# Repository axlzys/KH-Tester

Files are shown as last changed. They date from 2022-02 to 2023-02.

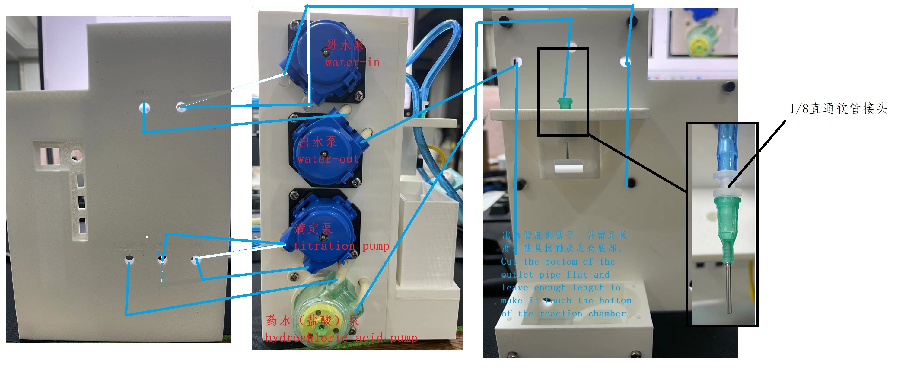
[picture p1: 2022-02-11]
管路连接.jpg

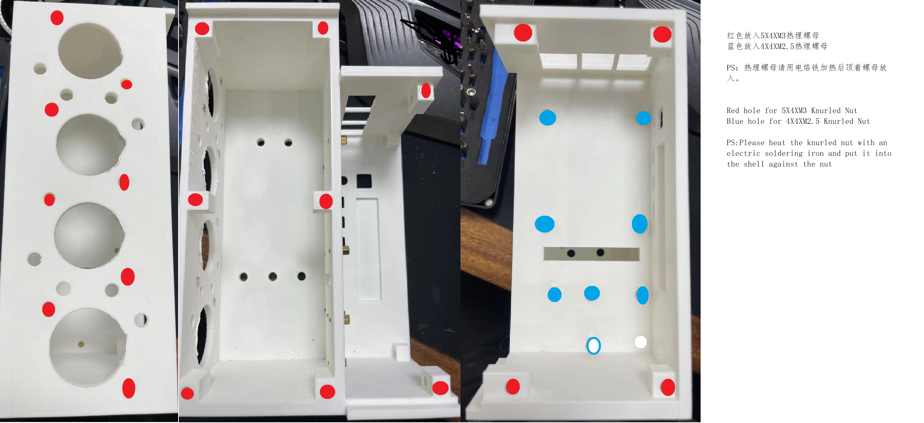
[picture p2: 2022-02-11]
孔位.jpg

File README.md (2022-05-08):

# KH-Tester
SSH PASSWORD IS: 123456 </br>
This open source project is an automatic KH test device (the automatic control KH code is not tested, use it with caution)</br>
The principle of this equipment is the hydrochloric acid titration method. Due to the selected peristaltic pump flow rate, dripper, reaction chamber volume and other reasons, the test accuracy is 0.1dkh, which basically meets the daily monitoring needs of sea tanks.</br>
The hydrochloric acid used for detection was 0.1N (0.1mol/L) standard solution. After testing, the detected wastewater can be directly discharged into the tank.</br>
This project follows the "GNU General Public License V3.0", you can carry out any secondary development and modification of this project, but DO NOT USE IT for commercial projects, and some functions have patents.</br>
Instructions in English translated by Google</br>

about the motor hat, maybe you can use the ADafruit motor hat,if you can change the code(about Raspi GPIO number)

rasberry pi img file :https://www.dropbox.com/s/r4e066tjngnfint/KH%20Tester.rar?dl=0

--------------------------------------------------------------------------------------------------------------------------------
SSH密码为：123456</br>
此开源项目目的在于造福广大鱼友，自动化KH测试设备（自动控制KH代码没有测试，谨慎使用）</br>
本设备原理为盐酸滴定法。因为选择的蠕动泵流量、滴头、反应仓容积等原因，测试精度为0.1dkh，基本满足海缸的日常监测需求。</br>
用于检测的盐酸为0.1N（0.1mol/L）标准溶液。经过测试，检测后的废水可以直接排入缸内。</br>
本项目的物料成本在1500元人民币左右（不计入3D打印外壳），主要成本在树莓派。</br>

本项目遵循《GNU通用公共许可证V3.0》，您可以对本项目进行任意二次开发，修改，但不得用于商业项目，部分功能已有专利。</br>

IMG文件：链接：https://pan.baidu.com/s/1cQux1sHFy6QSNtrp6qSavw 
提取码：5o4n

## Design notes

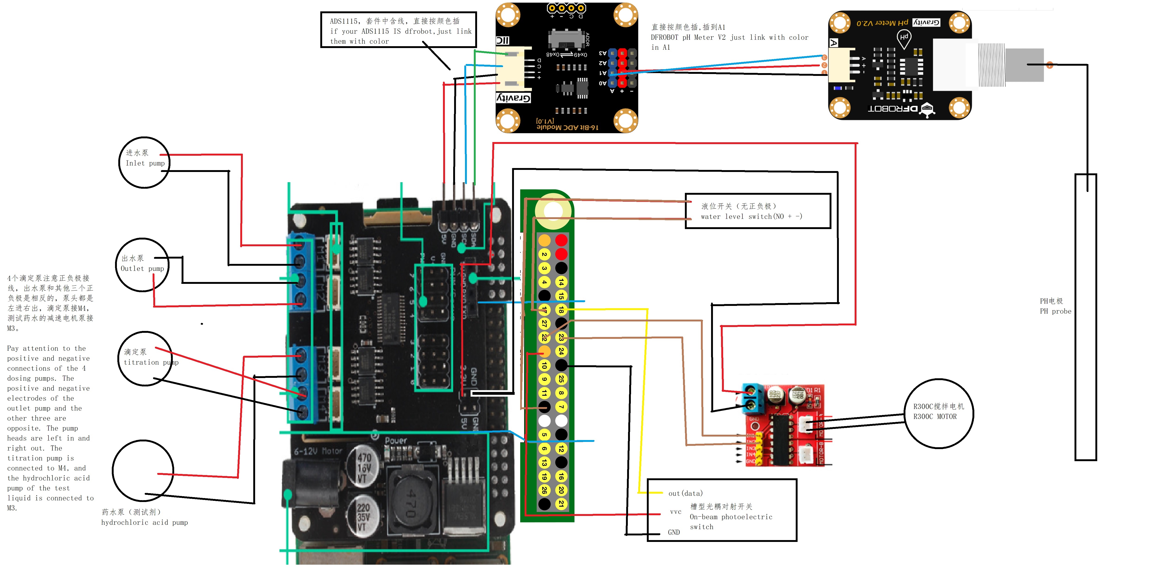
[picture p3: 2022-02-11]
电路连接.jpg

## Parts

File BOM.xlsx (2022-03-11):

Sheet: 中文
KH Tester BOM
NO. | Name | COUT
1 | 树莓派 | 1 | 我使用的树莓派型号是4B4G，你可以尝试3B或者其他版本，但是我没有测试
2 | 奇果派树莓派电机扩展板 | 1 |  | https://item.taobao.com/item.htm?spm=a1z10.3-c-s.w4002-23153264118.9.3ca568f9grf0pd&id=569721233878
3 | DFRobot I2C ADS1115 模数转换模块 | 1 |  | https://item.taobao.com/item.htm?spm=a1z10.3-c-s.w4002-23951518078.9.739f37fbMzMyT7&id=571089669237
4 | DFRobot 模拟PH计V2 | 1 |  | https://item.taobao.com/item.htm?spm=a1z10.3-c-s.w4002-23951518078.9.739f37fbMzMyT7&id=576606299761
5 | 2.5A 双路电机取得板模块 正反转PWM | 1 |  | https://detail.tmall.com/item.htm?id=18566053714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
6 | 液位开关 | 1 |  | https://detail.tmall.com/item.htm?id=547346980048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
7 | 槽型光耦对射开关 | 1 |  | https://detail.tmall.com/item.htm?id=609731076227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
8 | 卡默尔12V减速蠕动泵 | 1 | 链接中没有，请联系客服购买12V二级减速（B06）型号 | https://detail.tmall.com/item.htm?id=523285280850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
9 | 卡默尔12V蠕动泵 | 3 | NKP-DC-S10B，在卡默尔NKP下找
10 | 3*5滴定管 | 若干 | 建议5米
11 | 5X4XM3滚花热埋螺母 | 20 | 建议多买几个，所有螺丝螺栓除了铜的都建议买304不锈钢以上，316最好
12 | 4X4XM2.5滚花热埋螺母 | 9
13 | M3X10沉头螺栓 | 20
14 | M3X45沉头螺栓 | 2
15 | M2.5*5+6单头六角铜柱 | 10
16 | M2.5X5螺栓 | 10
17 | M2.5*11+3单头六角铜柱 | 4
18 | M2.6X10平尾自攻螺丝 | 4
19 | 杜邦线（母对母） | 若干 | 建议30CM
20 | 12V3A（5.5*2.5）电源适配器 | 1
21 | PH2.0公对母线 | 2 | 建议30CM
22 | 单头杜邦头+卡簧 | 若干
23 | 18G点胶针头（内径0.84mm） | 1
24 | 5V R300C直流电机 | 1 | 24.3*12.4 轴径2mm输出轴长6mm
25 | 1/8直通软管接头 | 8
26 | A型8X20磁力搅拌子 | 1
27 | 8X3铷磁铁 | 2
28 | 32G TF卡 | 1 | 建议买质量好点的
29 | 0.1N（0.1MOL/L）盐酸标准溶液 | 1 | 每次测试用量在1.5-2.2ML左右

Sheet: English
KH Tester BOM
NO. | Name | COUT
1 | rasberry pi | 1 | my model is 4B4G，not test or 3B or other
2 | Qiguo Pi Stepper Motor HAT for Raspberry Pi | 1 | I find it in ebay,you may use other motor hat,but I have no test | https://www.ebay.com/itm/383044999281
3 | DFRobot I2C ADS1115 | 1 |  | https://www.dfrobot.com/product-1730.html
4 | DFRobot Gravity: Analog pH Sensor/Meter Kit V2 | 1 |  | https://www.dfrobot.com/product-1782.html
5 | 2.5A 2-Way DC Step Motor Drive | 1 | https://www.ebay.com/itm/125008237434?hash=item1d1b12537a:g:leIAAOSwGHphlc58
6 | water-level switch 25MM | 1 |  | https://www.ebay.com/itm/234108273649
7 | IR Infrared Slotted Optical Speed Measuring Sensor | 1 |  | https://www.ebay.com/itm/253045605980
8 | Kamoer Dosing Pump 12V Reduction Gear Brush Pump | 1 | 12Vtwo slowdown gear B06 | https://www.aliexpress.com/item/32601056500.html?pdp_ext_f=%7B%22sku_id%22%3A%2266451658933%22%7D
9 | Kamoer NKP Peristaltic Pump | 3 | 12V Straight S10 | https://www.aliexpress.com/item/2021056985.html?pdp_ext_f=%7B%22sku_id%22%3A%2266540462983%22%7D
10 | 3*5K Silicon Tube | some | maybe 5M
11 | 5X4XM3 knurled nut | 20 | It is recommended to buy a few more, all screws and bolts except copper are recommended to buy 304 stainless steel or above, 316 is the best
12 | 4X4XM2.5 knurled nut | 9
13 | M3X10 bolt | 20
14 | M3X45 bolt | 2
15 | M2.5*5+6 Hexagonal copper column Single-headed | 10
16 | M2.5X5bolt | 10
17 | M2.5*11+3 Hexagonal copper column Single-headed | 4
18 | M2.6X10 self-tapping screw | 4
19 | Dupont Line(female to female) | some | maybe 30CM
20 | 12V3A（5.5*2.5）Power Adapter | 1
21 | PH2.0(male to female) | 2 | maybe 30CM
22 | Dupont Cable Female case and Pin | some
23 | flat Needle, 18 ga, | 1 | 1/2 in(12.7mm) Length（Inside Diameter: 0.033in,0.84mm）
24 | 5V RC-300 DC MOTOR | 1 | 24.3*12.4 ,output shaft length 6mm
25 | 1/8Straight-through tube connector | 8
26 | Magnetic Stirrer PTFE Olive Cone Type A | 1 | 8X20
27 | 8X3 Rubidium magnet | 2
28 | 32G TF card | 1
29 | 0.1N（0.1MOL/L）Hydrochloric acid | 1 | the tester need 1.5-2.2ML for one test

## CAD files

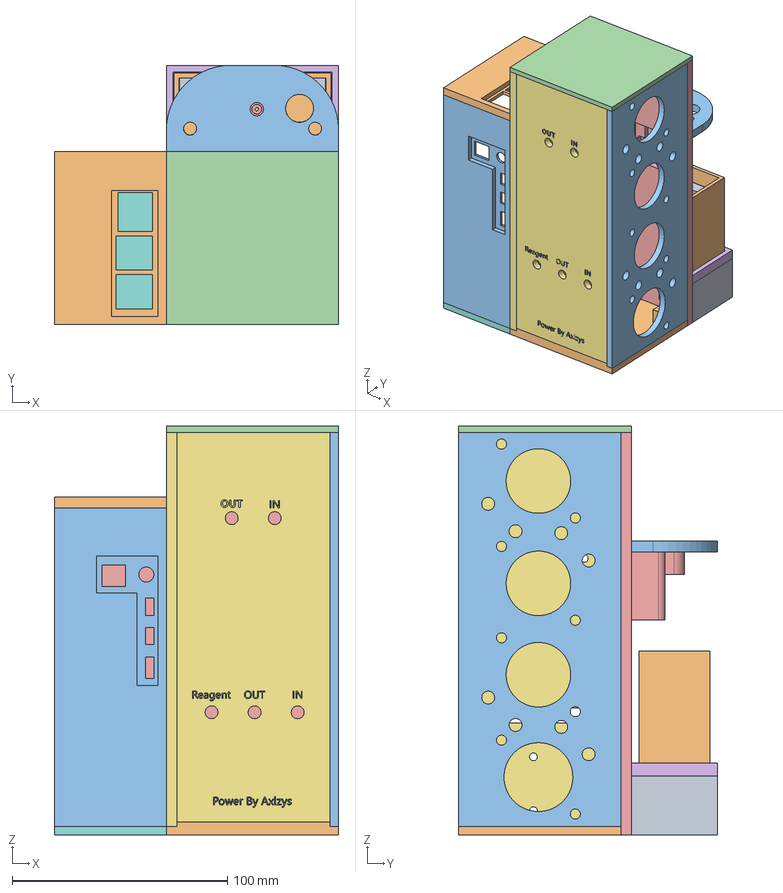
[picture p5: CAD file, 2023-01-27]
main.stp
132.0 x 120.5 x 190.0 mm
主机外壳（new）
光电开关架

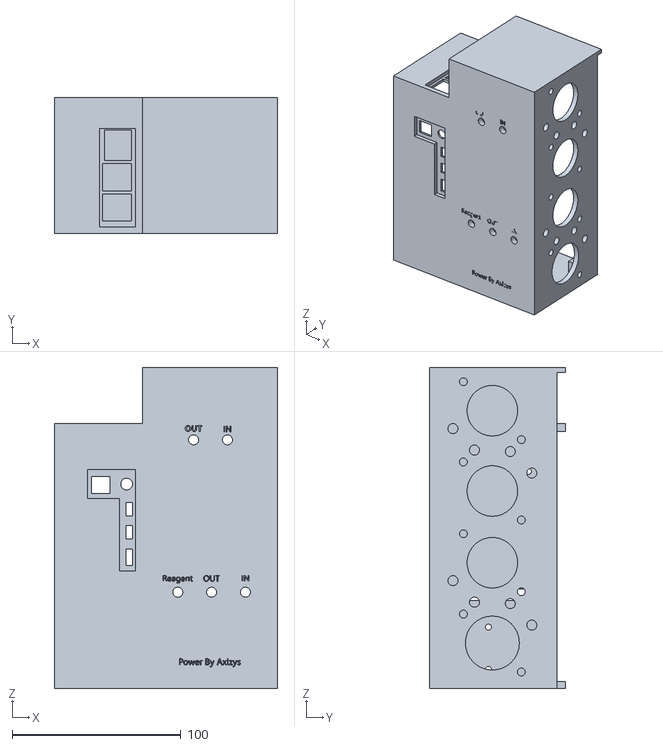
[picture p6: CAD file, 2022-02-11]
STL/main body.stl
132.0 x 80.5 x 190.0

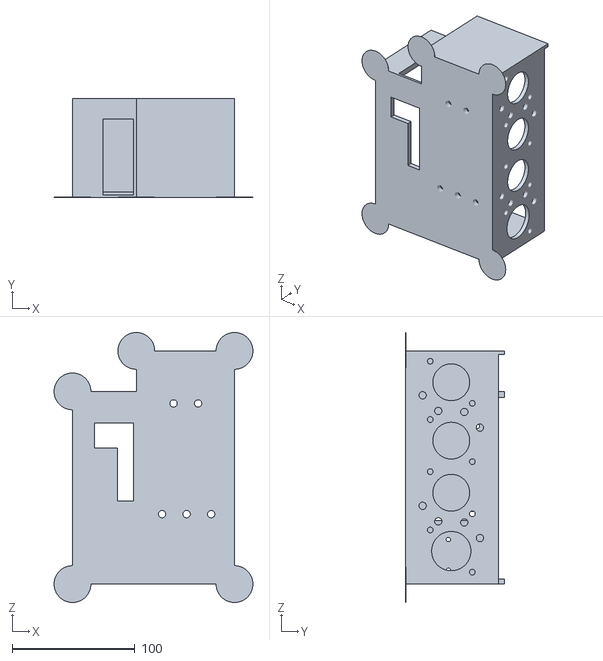
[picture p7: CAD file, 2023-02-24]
new modle made by Krheigh/Main body.stl
162.0 x 80.5 x 220.0

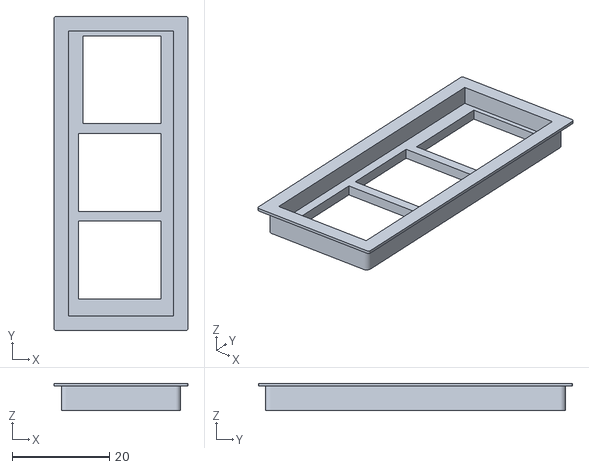
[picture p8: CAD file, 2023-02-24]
new modle made by Krheigh/Rpi 4 usb cover.stl
27.5 x 64.5 x 5.56

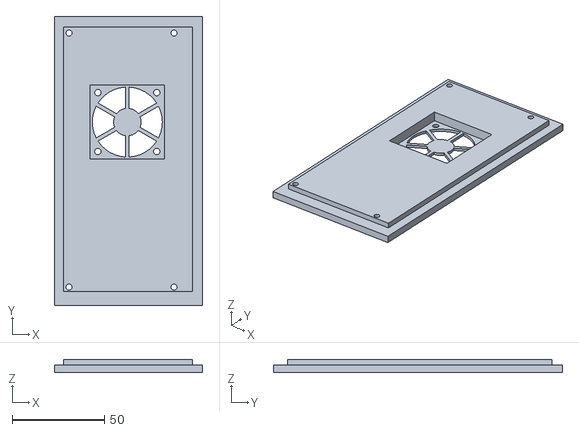
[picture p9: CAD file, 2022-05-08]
STL/cover with fan.stl
80.5 x 157.0 x 7.00

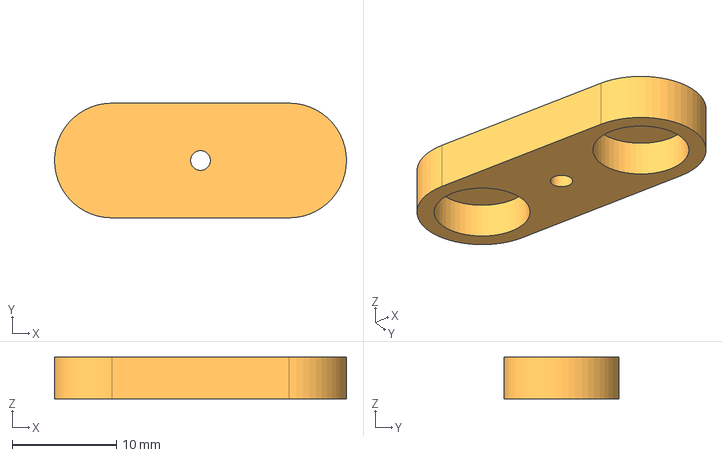
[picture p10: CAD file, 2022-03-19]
magnet holder.stp
28.0 x 11.0 x 4.00 mm

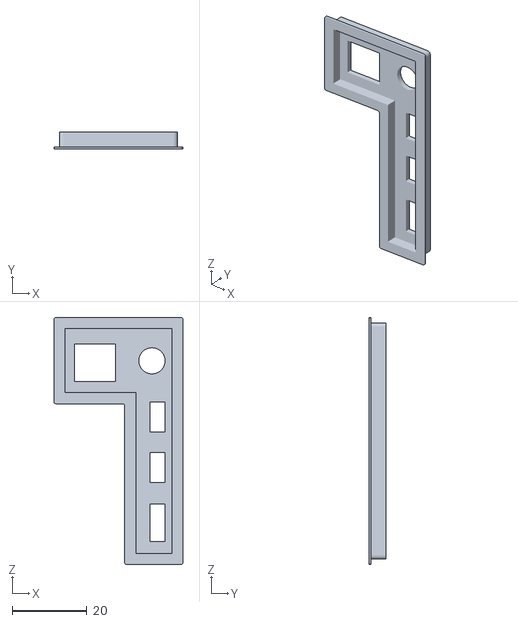
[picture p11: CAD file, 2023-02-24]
new modle made by Krheigh/Rpi 4 cover.stl
34.5 x 4.58 x 66.1

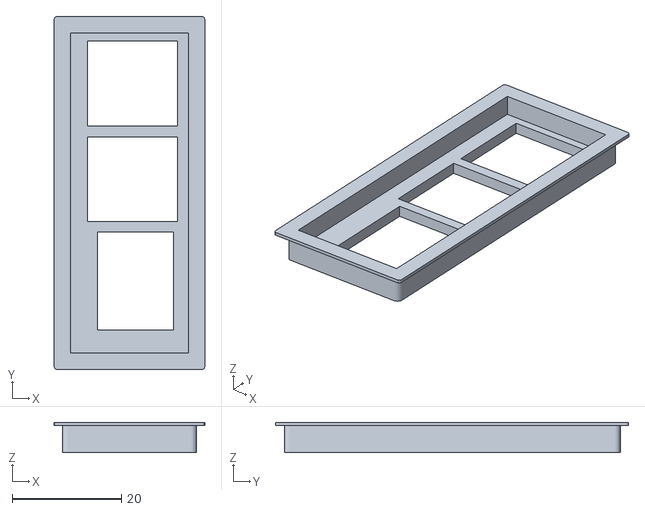
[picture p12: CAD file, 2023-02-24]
new modle made by Krheigh/Rpi 3 usb cover.stl
27.5 x 64.5 x 5.56

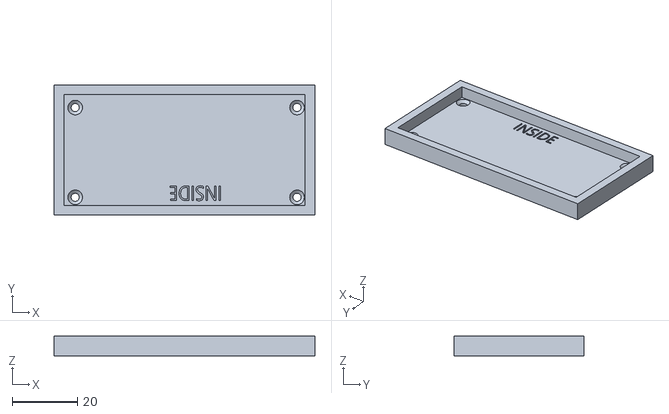
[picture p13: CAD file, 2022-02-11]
STL/stirring motor cover.stl
80.0 x 40.0 x 6.00

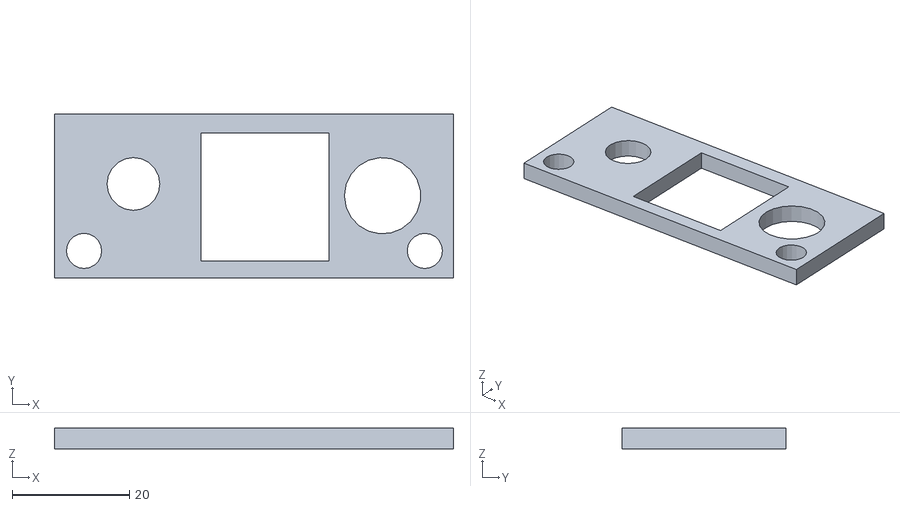
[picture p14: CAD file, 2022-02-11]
STL/water level switch bracket.stl
68.0 x 28.0 x 3.50

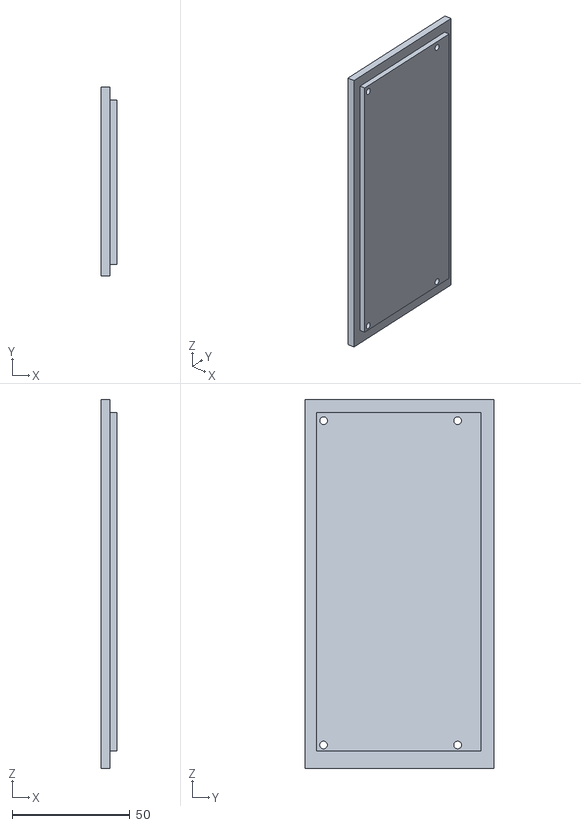
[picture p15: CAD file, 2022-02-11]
STL/side cover.stl
7.00 x 80.5 x 157.0

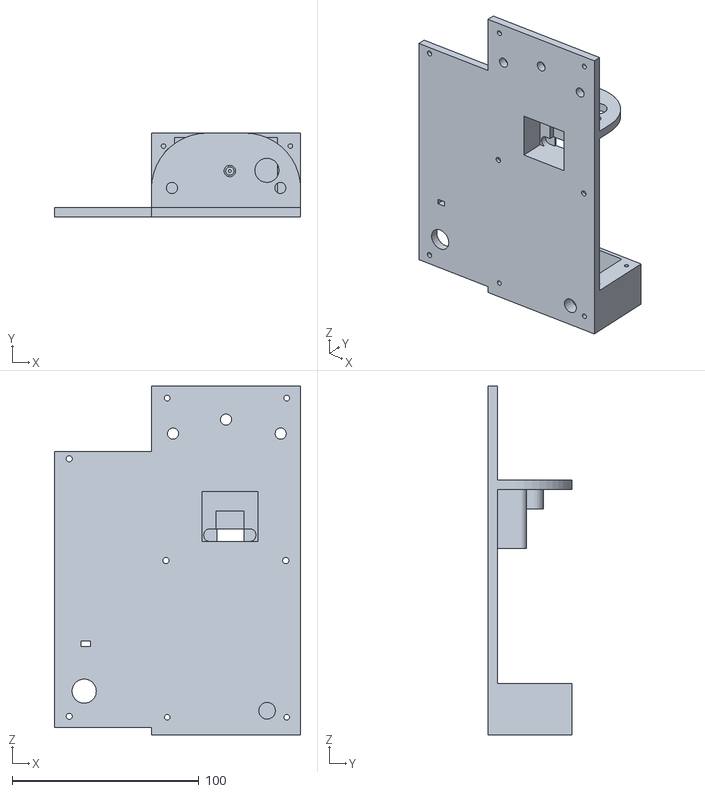
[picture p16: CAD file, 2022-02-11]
STL/front cover.stl
132.0 x 45.0 x 187.0

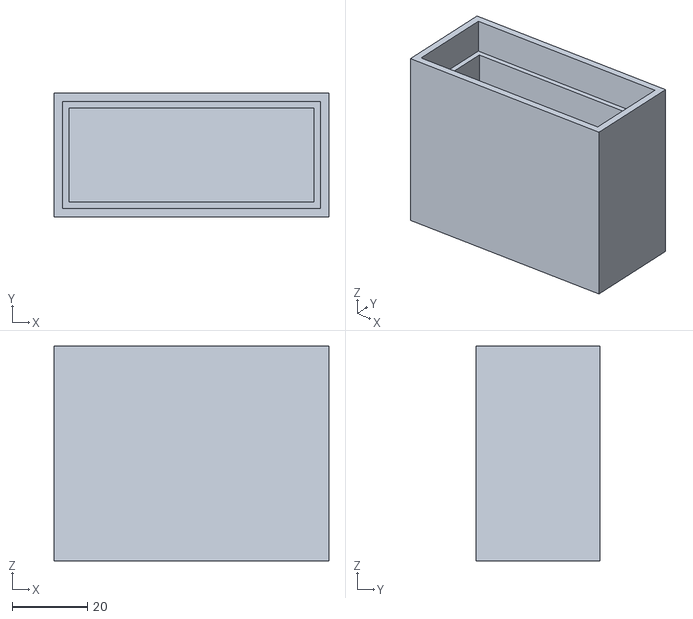
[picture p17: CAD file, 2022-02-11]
STL/reaction chamber.stl
73.0 x 33.0 x 57.0

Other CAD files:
STL/magnetic stirring bracket.stl
new modle made by Krheigh/Rpi 3 cover.stl
cover with fan.prt
magnet holder.prt
main.prt

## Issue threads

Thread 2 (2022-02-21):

非常感谢分享，已经全部装好，等周末开始开机测试。提一个小建议。

winter07, 2022-02-21:
建议把R300电机做高一点，磁铁和转子之间的空间比较大。电机上的那块3D模块可以做小一点，转子两头不能很好的吸住。我现在用的是KHG的模块，大小还是比较合适的。反应盒的材料还能换成别的吗？我担心3D打印的用久了会漏

axlzys, 2022-02-21:
>

我一开始用的pla会渗，后来用了petg，顶层5 走线3，目前一直没漏，，

Closed 2022-04-02.

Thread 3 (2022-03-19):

Which pumps?

guestisp, 2022-03-19:
Which pumps are needed ? It' wrote in chinese :-D

Kamoer KFS for the acid and KXS for the water ?

axlzys, 2022-03-19:
kfs 12V two slowdown gear （B06）for acid and NKP S10 for water，
in the file BOM.xlsx there are two sheets one is  in english,

Closed 2022-04-02.

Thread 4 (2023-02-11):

operating system

brunoalexsilva, 2023-02-11:
which operating system
are you using it on raspyberry, or is it not
Do I need any operating system?

axlzys, 2023-02-11:
i used Raspberry Pi OS X64 with Desktop.
And i uploaded img flie within the tester software to dropbox,the address you can find in readme.

brunoalexsilva, 2023-02-11:
just extract the file
img inside the boot folder of the operating system?
and configure the file
wpa_supplicant.conf?

axlzys, 2023-02-11:
just write the img file to your tf card and configure the wpa_supplicant.conf.
then put the tf card in to your raspberry.
but If you did not complete the assembly the software will not run.

brunoalexsilva, 2023-02-11:
I will try, thank you very much

brunoalexsilva, 2023-11-03:
Hello, I managed to buy all the accesses, but I encountered a difficulty in the project. I developed my algorithm on my personal computer, should I have developed the code already within the Raspberry operating system?
I'm having difficulty running the project, which folder within Raspberry do I need to copy the files to?

Thanks

cching1580, 2024-10-24:
@axlzys 我下载了然后解压文件是123，可是不是img 格式的，我用raspberry pi imager 写入可以吗？

brunoalexsilva, 2024-11-11:
> Did you make it work

Ainda estou com dificuldades para executar.

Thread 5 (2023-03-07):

Tritation and Reagent Pump

luksmbf, 2023-03-07:
Hi, I saw that you use 4 dosing pumps, and I'm a bit confuse about what one of them does (specifically the third one - titration). Below I described what I understood for what each pump do, please check my understanding.
- The first dosing pump, pumps water form the tank to the chamber.
- The second dosing pump, pumps water from the chamber to a resevoir or back to the tank after the test is complete.
- The third pump is called titration pump but I did not understand what ir pumps (from where to where).
- The fourth pump pumps the reagent hydrochloric acid to the chamber.

I'm going to try rebuild the eletronics and software of this project to use an ESP32.
Could you also check if my understanding of the test process (below).
1 - Pump water from tank to reaction chamber, checking it level.
2 - Check initial PH.
3 - Dose some  hydrochloric acid to reaction chamber.
4 - Stirr the liquid in chamber.
5 - Verify if the PH reached 4.
6 - Do the steps 3, 4 and 5 until gets PH to 4.
7 - Calculate PH.
8 - Pump the liquid out of the chamber.

axlzys, 2023-03-07:
The third pump is for KH balance,but it's dont work now.i have no time to finsh the cord.
The earliest idea was Set the target KH value first,and comparison of KH value and target value after each test,then add some KH buffer,until the test result is close to the target value.
about the test process:
1.clean the reaction chamber(include pump water from tank,Stirring reaction chamber,pump the liquid out)
2.pump the water from tank again.it's Always checks PH every 10 seconds.
3.Dose some hydrochloric acid to reaction chamber.Stirring during doseing hydrochloric acid.
4.when it's doseing,the PH will check after every hydrochloric acid dorps.until the PH<=4.5.
5.Calculate PH.(in that process if you set KH target,it Will decide whether to add KH buffer according to the value.but the code don't work now,The motor pins are wrong in the code)
6.Pump the liquid out.
7.pump water from tank to reaction chamber.

luksmbf, 2023-03-07:
Thank you very much for the explanation!

Closed 2023-03-07.

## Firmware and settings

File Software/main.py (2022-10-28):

#                 This software is part of the KH Tester
#                               Version 3.0
#                   Copyright (C) 2022 jiawei wu
#
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
import time
from flask import render_template, jsonify,request
from flask_moment import Moment
import datetime
from Tester import tester
from database import db,testResult,KHResult,timesleep,runtime,SampleV,PharmacyV,TargKH,KHpump
from app import app,scheduler


moment = Moment(app)
@app.route('/main')
@app.route('/')
def main():
    return render_template('main.html', time=datetime.datetime.utcnow())

@app.route('/KHhistry')
def KHhistry():
    KHResultlist = KHResult.query.order_by(KHResult.id.desc()).limit(50)
    return render_template('KHhistry.html',KHResultlist= KHResultlist)

@app.route('/setting')
def setting():
    return render_template('setting.html')

@app.route('/realtimePH')
def realtimePH():
    users = testResult.query.order_by(testResult.id.desc()).first()
    users= users.PHresult
    return str(users)

def autoreadPH():
    realtimePH = tester().readPH(1)
    PH1 = testResult(Date=datetime.datetime.now().strftime('%Y-%m-%d'),
                     Time=datetime.datetime.now().strftime('%H:%M:%S'), PHresult=realtimePH)
    db.session.add(PH1)
    db.session.commit()
    return str(realtimePH)

@app.route('/dbph')
def PHlist():
    users = testResult.query.order_by(testResult.id.desc()).limit(10)
    users = users[::-1]
    x_data = [i.Time for i in users]
    y_data = [i.PHresult for i in users]

    data = {
        'x_data': x_data,
        'y_data': y_data
    }
    return jsonify(data)

@app.route('/CalibrationPH')
def CalibrationPH1():
    aa = tester().CalibrationPH(1)
    return jsonify(aa)

@app.route('/CalibrationKH')
def CalibrationKH1():
    aa = tester().CalibrationPH(1)
    return jsonify(aa)

@app.route('/realtimeKH')
def realtimeKH():
    users = KHResult.query.order_by(KHResult.id.desc()).first()
    users = users.KHresult
    return jsonify(users)

@app.route('/runkhtest')
def runkhtest():
    Samplev = SampleV.query.order_by(SampleV.id.desc()).first()
    samplev = Samplev.SPV
    pharmacyV = PharmacyV.query.order_by(PharmacyV.id.desc()).first()
    pharmacyV = pharmacyV.PHV
    aciv= pharmacyV/100
    lastkhtime = runtime.query.order_by(runtime.id.desc()).first()
    lastkhtime = lastkhtime.Time
    lastkhdata = runtime.query.order_by(runtime.id.desc()).first()
    lastkhdata = lastkhdata.Date
    lastkh = lastkhdata + lastkhtime
    lastkhdatatime = datetime.datetime.strptime(lastkh, '%Y-%m-%d%H:%M:%S')
    time14 = lastkhdatatime + datetime.timedelta(minutes=15)
    if time14 < datetime.datetime.now():
        runtime1 = runtime(Date=datetime.datetime.now().strftime('%Y-%m-%d'),
                           Time=datetime.datetime.now().strftime('%H:%M:%S'))
        db.session.add(runtime1)
        db.session.commit()
        drops = tester().KHtester()
        if drops != False:
            drops = drops
            VHCL = drops * aciv
            khresult = (VHCL / samplev) * 280
            khresult2 = round(khresult, 1)
            KH1 = KHResult(Date=datetime.datetime.now().strftime('%Y-%m-%d'),
                           Time=datetime.datetime.now().strftime('%H:%M:%S'), KHresult=khresult2)
            db.session.add(KH1)
            db.session.commit()
            tester().drainbot()
            tester().fillbot()
            return jsonify(khresult2)
        else:
            return "反应仓进水超时，请检查进水管，液位开关等。"
    else:
        return jsonify("15分钟内刚进行过测试，请稍后再试")

@app.route('/dbkh')
def KHlist():
    users = KHResult.query.order_by(KHResult.id.desc()).limit(10)
    users = users[::-1]
    x_data = [i.Time for i in users]
    y_data = [i.KHresult for i in users]

    data = {
        'x_data': x_data,
        'y_data': y_data
    }
    return jsonify(data)


@app.route('/test1')
def printTime():

    lastkhtime = KHResult.query.order_by(KHResult.id.desc()).first()
    lastkhtime = lastkhtime.Time
    lastkhdata = KHResult.query.order_by(KHResult.id.desc()).first()
    lastkhdata = lastkhdata.Date
    lastkh = lastkhdata + lastkhtime
    lastkhdatatime = datetime.datetime.strptime(lastkh,'%Y-%m-%d%H:%M:%S')
    time14 = lastkhdatatime + datetime.timedelta(minutes=15)

    if time14 > datetime.datetime.now():

        print(lastkhdatatime)
    #print(time14)
    else:
        print(datetime.datetime.now())

    #print(time14 - now)
    return 'ok'

@app.route('/testpwm1')
def testpwm1():
    time11 = timesleep.query.order_by(timesleep.id.desc()).first()
    time12 = time11.time

    return jsonify(time12)



@app.route('/getjson',methods=['GET','POST'])
def getjson():
    a = request.json
    if a:
        data = a['opt']
        data = int(data)
        TIME = timesleep(time = data)
        db.session.add(TIME)
        db.session.commit()
        time14 = data * 3600
    for job in scheduler.get_jobs():
            scheduler.modify_job(id = 'job2', trigger='interval', seconds=time14)
    return jsonify(data)

@app.route('/CalibrationSPV')
def CalibrationSPV():
    tester().drainbot()
    tester().fillbot()
    return jsonify("反应仓容积校准完成，请拿出反应仓测量容积并输入。")

@app.route('/getSPV',methods=['GET','POST'])
def getSPV():
    b= request.json
    if b:
        data1 = b['opt1']
        data1 = float(data1)
        SPV1 = SampleV(SPV = data1)
        db.session.add(SPV1)
        db.session.commit()
    return jsonify(data1)

@app.route('/readSPV')
def readSPV():
    Samplev = SampleV.query.order_by(SampleV.id.desc()).first()
    Samplev = Samplev.SPV
    return jsonify(Samplev)

@app.route('/CalibrationACIV')
def CalibrationACIV():
    tester().CalibrationACIVcore()
    return jsonify("药水泵流量校准完成，请拿测量容积并输入。")

@app.route('/getACIV',methods=['GET','POST'])
def getACIV():
    c = request.json
    if c:
        data1 = c['opt2']
        data1 = float(data1)
        ACIV1 = PharmacyV(PHV = data1)
        db.session.add(ACIV1)
        db.session.commit()
    return jsonify(data1)

@app.route('/readACIV')
def readACIV():
    pharmacyV = PharmacyV.query.order_by(PharmacyV.id.desc()).first()
    pharmacyV = pharmacyV.PHV
    return jsonify(pharmacyV)

@app.route('/CalibrationKHpump')
def CalibrationKHpump():
    tester().KHpumpon()
    time.sleep(10)
    tester().KHpumpoff()
    return jsonify("滴定泵流量校准完成，请拿测量容积并输入。")

@app.route('/getKHpump',methods=['GET','POST'])
def getKHpump():
    c = request.json
    if c:
        data1 = c['opt3']
        data1 = float(data1)
        KHpump1 = KHpump(KHpumpV = data1)
        db.session.add(KHpump1)
        db.session.commit()
    return jsonify(data1)

@app.route('/readKHpump')
def readKHpump():
    kHpump = KHpump.query.order_by(KHpump.id.desc()).first()
    kHpump = kHpump.KHpumpV
    kHpump= kHpump
    return jsonify(kHpump)

@app.route('/gettar',methods=['GET','POST'])
def gettar():
    c = request.json
    if c:
        data2 = c['opt2']
        data2 = float(data2)
        TargKH1 = TargKH(targetKH = data2)
        db.session.add(TargKH1)
        db.session.commit()
    return jsonify(data2)

@app.route('/readtar')
def readtar():
    targKH = TargKH.query.order_by(TargKH.id.desc()).first()
    targKH = targKH.targetKH
    targKH= targKH
    return jsonify(targKH)

@app.route('/Inpumpon')
def Inpumpon():
    tester().Inpumpon()

@app.route('/Inpumpoff')
def Inpumpoff():
    tester().Inpumpoff()

@app.route('/Outpumpon')
def Outpumpon():
    tester().Outpumpon()

@app.route('/Outpumpoff')
def Outpumpoff():
    tester().Outpumpoff()

@app.route('/KHpumpon')
def KHpumpon():
    tester().KHpumpon()

@app.route('/KHpumpoff')
def KHpumpoff():
    tester().KHpumpoff()

@app.route('/pharmacypumpon')
def pharmacypumpon():
    tester().pharmacypumpon()

@app.route('/pharmacypumpoff')
def pharmacypumpoff():
    tester().pharmacypumpoff()

@app.route('/getkhtime')
def getkhtime():
    time20 = timesleep.query.order_by(timesleep.id.desc()).first()
    time21 = time20.time
    time21 = time21 * 3600
    return time21

@app.route('/autorunkhtest')
def autorun():
    lastkhtime = runtime.query.order_by(runtime.id.desc()).first()
    lastkhtime = lastkhtime.Time
    lastkhdata = runtime.query.order_by(runtime.id.desc()).first()
    lastkhdata = lastkhdata.Date
    lastkh = lastkhdata + lastkhtime
    lastkhdatatime = datetime.datetime.strptime(lastkh, '%Y-%m-%d%H:%M:%S')
    time14 = lastkhdatatime + datetime.timedelta(minutes=10)
    if time14 < datetime.datetime.now():
        runtime1 = runtime(Date=datetime.datetime.now().strftime('%Y-%m-%d'),
                           Time=datetime.datetime.now().strftime('%H:%M:%S'))
        db.session.add(runtime1)
        db.session.commit()
        return autorunkhtest()
    else:
        scheduler.pause_job("job2")
        time.sleep(10)
        scheduler.resume_job("job2")
        return "10分钟内进行过手动测试，自动测试自动延期。"

def autorunkhtest():
    targKH = TargKH.query.order_by(TargKH.id.desc()).first()
    targKH = targKH.targetKH
    tar = targKH
    Samplev = SampleV.query.order_by(SampleV.id.desc()).first()
    samplev = Samplev.SPV
    pharmacyV = PharmacyV.query.order_by(PharmacyV.id.desc()).first()
    pharmacyV = pharmacyV.PHV
    aciv = pharmacyV / 100
    drops = tester().KHtester()
    if drops != False:
        drops = drops
        VHCL = drops * aciv
        khresult = (VHCL/samplev)*280
        khresult2 = round(khresult,1)
        if tar == 0:
            tester().KHpumpoff()
        elif tar - khresult2 > 0 and tar - khresult2 <0.5:
            tester().KHpumpoff()
        elif tar - khresult2 >= 0.5 and tar - khresult2 <1:
            tester().KHpumpon()
            time.sleep(3)
            tester().KHpumpoff()
        elif tar - khresult2 >= 1 and tar - khresult2 <2:
            tester().KHpumpon()
            time.sleep(6)
            tester().KHpumpoff()
        elif tar - khresult2 >= 2:
            tester().KHpumpon()
            time.sleep(10)
            tester().KHpumpoff()
        KH1 = KHResult(Date=datetime.datetime.now().strftime('%Y-%m-%d') ,Time = datetime.datetime.now().strftime('%H:%M:%S'),KHresult = khresult2,ADDKH = 1)
        db.session.add(KH1)
        db.session.commit()
        tester().drainbot()
        tester().fillbot()
        return jsonify(khresult2)
    else:
        return "反应仓进水超时，请检查进水管，液位开关等。"

@app.route('/AutoBalanceKH')
def AutoBalanceKH():
    tester().pharmacypump(1)
    return "OK"

@app.route('/stir')
def stirmix():
    tester().stir()
    return "OK"

class SchedulerConfig(object):
    JOBS = [
        {
            'id': 'job2', # 任务id
            'func': '__main__:autorun', # 任务执行程序
            'args': None, # 执行程序参数
            'trigger': 'interval', # 任务执行类型，定时器
            'seconds': getkhtime(), # 任务执行时间，单位秒
        },
        {
            'id': 'job3',  # 任务id
            'func': '__main__:autoreadPH',  # 任务执行程序
            'args': None,  # 执行程序参数
            'trigger': 'interval',  # 任务执行类型，定时器
            'seconds': 10,  # 任务执行时间，单位秒
        }
    ]


app.config.from_object(SchedulerConfig())

if __name__ == '__main__':
    scheduler.init_app(app)  # 把任务列表载入实例flask
    scheduler.start()  # 启动任务计划
    app.run(host='0.0.0.0', port=5000, debug=False)

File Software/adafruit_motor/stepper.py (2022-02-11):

# The MIT License (MIT)
#
# Copyright (c) 2017 Scott Shawcroft for Adafruit Industries LLC
#
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
# THE SOFTWARE IS PROVIDED "AS IS", WITHOUT WARRANTY OF ANY KIND, EXPRESS OR
# IMPLIED, INCLUDING BUT NOT LIMITED TO THE WARRANTIES OF MERCHANTABILITY,
# FITNESS FOR A PARTICULAR PURPOSE AND NONINFRINGEMENT. IN NO EVENT SHALL THE
# AUTHORS OR COPYRIGHT HOLDERS BE LIABLE FOR ANY CLAIM, DAMAGES OR OTHER
# LIABILITY, WHETHER IN AN ACTION OF CONTRACT, TORT OR OTHERWISE, ARISING FROM,
# OUT OF OR IN CONNECTION WITH THE SOFTWARE OR THE USE OR OTHER DEALINGS IN
# THE SOFTWARE.
"""
`adafruit_motor.stepper`
====================================================

Stepper motors feature multiple wire coils that are used to rotate the magnets connected to the
motor shaft in a precise way. Each increment of the motor is called a step. Stepper motors have a
varying number of steps per rotation so check the motor's documentation to determine exactly how
precise each step is.

* Author(s): Tony DiCola, Scott Shawcroft
"""

import math

from micropython import const

__version__ = "3.2.3"
__repo__ = "https://github.com/adafruit/Adafruit_CircuitPython_Motor.git"

# Stepper Motor Shield/Wing Driver
# Based on Adafruit Motorshield library:
# https://github.com/adafruit/Adafruit_Motor_Shield_V2_Library

# Constants that specify the direction and style of steps.
FORWARD = const(1)
"""Step forward"""
BACKWARD = const(2)
""""Step backward"""
SINGLE = const(1)
"""Step so that each step only activates a single coil"""
DOUBLE = const(2)
"""Step so that each step only activates two coils to produce more torque."""
INTERLEAVE = const(3)
"""Step half a step to alternate between single coil and double coil steps."""
MICROSTEP = const(4)
"""Step a fraction of a step by partially activating two neighboring coils. Step size is determined
   by ``microsteps`` constructor argument."""

_SINGLE_STEPS = bytes([0b0010, 0b0100, 0b0001, 0b1000])

_DOUBLE_STEPS = bytes([0b1010, 0b0110, 0b0101, 0b1001])

_INTERLEAVE_STEPS = bytes(
    [0b1010, 0b0010, 0b0110, 0b0100, 0b0101, 0b0001, 0b1001, 0b1000]
)


class StepperMotor:
    """A bipolar stepper motor or four coil unipolar motor. The use of microstepping requires
    pins that can output PWM. For non-microstepping, can set microsteps to None and use
    digital out pins.

    **PWM**

    :param ~pwmio.PWMOut ain1: `pwmio.PWMOut`-compatible output connected to the driver for
      the first coil (unipolar) or first input to first coil (bipolar).
    :param ~pwmio.PWMOut ain2: `pwmio.PWMOut`-compatible output connected to the driver for
      the third coil (unipolar) or second input to first coil (bipolar).
    :param ~pwmio.PWMOut bin1: `pwmio.PWMOut`-compatible output connected to the driver for
      the second coil (unipolar) or second input to second coil (bipolar).
    :param ~pwmio.PWMOut bin2: `pwmio.PWMOut`-compatible output connected to the driver for
      the fourth coil (unipolar) or second input to second coil (bipolar).
    :param int microsteps: Number of microsteps between full steps. Must be at least 2 and even.

    **Digital Out**

    :param ~digitalio.DigitalInOut ain1: `digitalio.DigitalInOut`-compatible output connected to
      the driver for the first coil (unipolar) or first input to first coil (bipolar).
    :param ~digitalio.DigitalInOut ain2: `digitalio.DigitalInOut`-compatible output connected to
      the driver for the third coil (unipolar) or second input to first coil (bipolar).
    :param ~digitalio.DigitalInOut bin1: `digitalio.DigitalInOut`-compatible output connected to
      the driver for the second coil (unipolar) or first input to second coil (bipolar).
    :param ~digitalio.DigitalInOut bin2: `digitalio.DigitalInOut`-compatible output connected to
      the driver for the fourth coil (unipolar) or second input to second coil (bipolar).
    :param microsteps: set to `None`
    """

    def __init__(self, ain1, ain2, bin1, bin2, *, microsteps=16):
        if microsteps is None:
            #
            # Digital IO Pins
            #
            self._steps = None
            self._coil = (ain1, ain2, bin1, bin2)
        else:
            #
            # PWM Pins
            #
            # set a safe pwm freq for each output
            self._coil = (ain2, bin1, ain1, bin2)
            for i in range(4):
                if self._coil[i].frequency < 1500:
                    self._coil[i].frequency = 2000
            if microsteps < 2:
                raise ValueError("Microsteps must be at least 2")
            if microsteps % 2 == 1:
                raise ValueError("Microsteps must be even")
            self._curve = [
                int(round(0xFFFF * math.sin(math.pi / (2 * microsteps) * i)))
                for i in range(microsteps + 1)
            ]
        self._current_microstep = 0
        self._microsteps = microsteps
        self._update_coils()

    def _update_coils(self, *, microstepping=False):
        if self._microsteps is None:
            #
            # Digital IO Pins
            #
            # Get coil activation sequence
            if self._steps is None:
                steps = 0b0000
            else:
                steps = self._steps[self._current_microstep % len(self._steps)]
            # Energize coils as appropriate:
            for i, coil in enumerate(self._coil):
                coil.value = (steps >> i) & 0x01
        else:
            #
            # PWM Pins
            #
            duty_cycles = [0, 0, 0, 0]
            trailing_coil = (self._current_microstep // self._microsteps) % 4
            leading_coil = (trailing_coil + 1) % 4
            microstep = self._current_microstep % self._microsteps
            duty_cycles[leading_coil] = self._curve[microstep]
            duty_cycles[trailing_coil] = self._curve[self._microsteps - microstep]

            # This ensures DOUBLE steps use full torque. Without it, we'd use
            #  partial torque from the microstepping curve (0xb504).
            if not microstepping and (
                duty_cycles[leading_coil] == duty_cycles[trailing_coil]
                and duty_cycles[leading_coil] > 0
            ):
                duty_cycles[leading_coil] = 0xFFFF
                duty_cycles[trailing_coil] = 0xFFFF

            # Energize coils as appropriate:
            for i in range(4):
                self._coil[i].duty_cycle = duty_cycles[i]

    def release(self):
        """Releases all the coils so the motor can free spin, also won't use any power"""
        # De-energize coils:
        for coil in self._coil:
            if self._microsteps is None:
                coil.value = 0
            else:
                coil.duty_cycle = 0
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

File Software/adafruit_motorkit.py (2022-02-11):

# The MIT License (MIT)
#
# Copyright (c) 2017 Scott Shawcroft for Adafruit Industries
# Copyright (c) 2018 Kattni Rembor for Adafruit Industries
#
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
# THE SOFTWARE IS PROVIDED "AS IS", WITHOUT WARRANTY OF ANY KIND, EXPRESS OR
# IMPLIED, INCLUDING BUT NOT LIMITED TO THE WARRANTIES OF MERCHANTABILITY,
# FITNESS FOR A PARTICULAR PURPOSE AND NONINFRINGEMENT. IN NO EVENT SHALL THE
# AUTHORS OR COPYRIGHT HOLDERS BE LIABLE FOR ANY CLAIM, DAMAGES OR OTHER
# LIABILITY, WHETHER IN AN ACTION OF CONTRACT, TORT OR OTHERWISE, ARISING FROM,
# OUT OF OR IN CONNECTION WITH THE SOFTWARE OR THE USE OR OTHER DEALINGS IN
# THE SOFTWARE.
"""
`adafruit_motorkit`
====================================================

CircuitPython helper library for DC & Stepper Motor FeatherWing, Shield, and Pi Hat kits.

* Author(s): Scott Shawcroft, Kattni Rembor

Implementation Notes
--------------------

**Hardware:**

   "* `DC Motor + Stepper FeatherWing <https://www.adafruit.com/product/2927>`_"
   "* `Adafruit Motor/Stepper/Servo Shield for Arduino v2 Kit
   <https://www.adafruit.com/product/1438>`_"
   "* `Adafruit DC & Stepper Motor HAT for Raspberry Pi - Mini Kit
   <https://www.adafruit.com/product/2348>`_"

**Software and Dependencies:**

* Adafruit CircuitPython firmware for the supported boards:
  https://github.com/adafruit/circuitpython/releases

 * Adafruit's Bus Device library: https://github.com/adafruit/Adafruit_CircuitPython_BusDevice
 * Adafruit's Register library: https://github.com/adafruit/Adafruit_CircuitPython_Register
 * Adafruit's PCA9685 library: https://github.com/adafruit/Adafruit_CircuitPython_PCA9685
 * Adafruit's Motor library: https://github.com/adafruit/Adafruit_CircuitPython_Motor

"""


import board
from adafruit_pca9685 import PCA9685

__version__ = "1.5.4"
__repo__ = "https://github.com/adafruit/Adafruit_CircuitPython_MotorKit.git"


class MotorKit:
    """Class representing an Adafruit DC & Stepper Motor FeatherWing, Shield or Pi Hat kit.

       Automatically uses the I2C bus on a Feather, Metro or Raspberry Pi if no I2C bus
       is supplied.

       Alternately, if using with multiple I2C devices, you can specify the I2C bus."""

    def __init__(self, address=0x60, i2c=None, steppers_microsteps=16):
        self._motor1 = None
        self._motor2 = None
        self._motor3 = None
        self._motor4 = None
        self._stepper1 = None
        self._stepper2 = None
        if i2c is None:
            i2c = board.I2C()
            
        self._pca = PCA9685(i2c, address=address)
        self._pca.frequency = 1600
        self._steppers_microsteps = steppers_microsteps

    # We can save memory usage (~300 bytes) by deduplicating the construction of the objects for
    # each motor. This saves both code size and the number of raw strings (the error message)
    # stored. The same technique is a net loss for stepper because there is less duplication.
    def _motor(self, motor_name, channels, stepper_name):
        from adafruit_motor import motor  # pylint: disable=import-outside-toplevel

        motor_name = "_motor" + str(motor_name)
        stepper_name = "_stepper" + str(stepper_name)
        if not getattr(self, motor_name):
            if getattr(self, stepper_name):
                raise RuntimeError(
                    "Cannot use {} at the same time as {}.".format(
                        motor_name[1:], stepper_name[1:]
                    )
                )
            self._pca.channels[channels[0]].duty_cycle = 0xFFFF
            setattr(
                self,
                motor_name,
                motor.DCMotor(
                    self._pca.channels[channels[1]], self._pca.channels[channels[2]]
                ),
            )
        return getattr(self, motor_name)

    @property
    def motor1(self):
        """:py:class:``~adafruit_motor.motor.DCMotor`` controls for motor 1.

            The following image shows the location of the M1 terminal on the DC/Stepper FeatherWing.
            The label on the FeatherWing is found on the bottom of the board.
            The terminal is labeled on the top of the Shield and Pi Hat.

            .. image :: ../docs/_static/motor_featherwing/m1.jpg
              :alt: Motor 1 location

            This example moves the motor forwards for one fifth of a second at full speed.

            .. code-block:: python

                import time
                from adafruit_motorkit import motorkit

                kit = MotorKit()

                kit.motor1.throttle = 1.0
                time.sleep(0.2)

                kit.motor1.throttle = 0
        """
        return self._motor(1, (8, 11, 10), 1)

    @property
    def motor2(self):
        """:py:class:``~adafruit_motor.motor.DCMotor`` controls for motor 2.

            The following image shows the location of the M2 terminal on the DC/Stepper FeatherWing.
            The label on the FeatherWing is found on the bottom of the board.
            The terminal is labeled on the top of the Shield and Pi Hat.

            .. image :: ../docs/_static/motor_featherwing/m2.jpg
              :alt: Motor 2 location

            This example moves the motor forwards for one fifth of a second at full speed.

            .. code-block:: python

                import time
                from adafruit_motorkit import motorkit

                kit = MotorKit()

                kit.motor2.throttle = 1.0
                time.sleep(0.2)

                kit.motor1.throttle = 0
        """
        return self._motor(2, (13, 9, 8), 1)

    @property
    def motor3(self):
        """:py:class:``~adafruit_motor.motor.DCMotor`` controls for motor 3.

            The following image shows the location of the M2 terminal on the DC/Stepper FeatherWing.
            The label on the FeatherWing is found on the bottom of the board.
            The terminal is labeled on the top of the Shield and Pi Hat.

            .. image :: ../docs/_static/motor_featherwing/m3.jpg
              :alt: Motor 3 location

            This example moves the motor forwards for one fifth of a second at full speed.

            .. code-block:: python

                import time
                from adafruit_motorkit import motorkit

                kit = MotorKit()

                kit.motor3.throttle = 1.0
                time.sleep(0.2)

                kit.motor1.throttle = 0
        """
        return self._motor(3, (2, 15, 14), 2)

    @property
    def motor4(self):
        """:py:class:``~adafruit_motor.motor.DCMotor`` controls for motor 4.

            .. image :: ../docs/_static/motor_featherwing/m4.jpg
              :alt: Motor 4 location

            This example moves the motor forwards for one fifth of a second at full speed.

            .. code-block:: python

                import time
                from adafruit_motorkit import motorkit

                kit = MotorKit()

                kit.motor4.throttle = 1.0
                time.sleep(0.2)
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

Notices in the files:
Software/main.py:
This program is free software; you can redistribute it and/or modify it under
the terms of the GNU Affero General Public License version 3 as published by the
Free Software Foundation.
